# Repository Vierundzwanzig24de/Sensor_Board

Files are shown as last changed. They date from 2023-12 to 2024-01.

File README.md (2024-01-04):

# Sensor Board V1

## Platine in Betrieb nehmen:
1. Keine Fuses einlöten, reverse polarity testen (Q1201)
	- Q1201 Pin 3 liegt Versorgungsspannung an
	- V_IN LED (D1210) leuchtet
	- F_Vdrive einlöten, Vdrive LED (D1206) leuchtet
2. Buck converter:
	- F_BUCK (F1201) einlöten
	- U1201 Pin 1 liegen 6V an
	- U1202 Pin 2 liegen 5V an
	- U1203 Pin 2 liegen 5V an
3. LDOs:
	- F_5VA, F_5V und F_3V3 nacheinander einlöten und Ausgänge testen
	- 5VA, 5V und 3.3V LEDs leuchten auf
	- Versorgung wegnehmen und F_USB einlöten
	- USB Versorgung anschließen
	- V_IN, Vdrive und 5VA LEDs bleiben aus, 5V und 3.3V leuchten
	- USB Jumper links setzen (Pins 2+3), 5VA LED leuchtet
	- Spannung an U1203 Pin 2 ist ~0V
	- USB Jumper alle Pins verbinden
	- Spannung an U1202 Pin 2 ist ~0V
	- Eingangsspannung verbinden, V_IN und Vdrive leuchten, Stromverbrauch normal
	- Spannung über D1204 und D1205 messen, danach USB Jumper rechts setzen (Pins 1+2)
	- USB Versorgung trennen, Ausgangsspannung U1202 vergleichen zwischen USB und ohne -> D1204 überbrücken? Wenn ja, Jumper USB nur noch wechseln zwischen 1/2 und 2/3
4. STM32:
	- ST-Link verbinden und Testprogramm aufspielen
	- STATUS LED blinkt
	- Versorgungsspannung wegnehmen
	- USB Versorgung verbinden und erneut Testprogramm aufspielen
	- STATUS LED blinkt immer noch
	
## Prüfen:
- 74HC595 Ausgangsspannung an PU/PD Widerständen!
- Flankensteilheit Halbbrücken einstellen

## Für V2:
- Halbbrücken näher an Stecker (Halbbrücken, 1A-Profets, Buck converter)
- STM um 90° drehen
- USB Stecker weiter herausstehen lassen
- kleinere Gehäuse für ICs nutzen
- Level shifter für 74HC595 nicht notwendig
- 3.3V Outputs??
- Umschalten Ausgangsspannung per Software
- Umschalten USB Versorgung per Software?? (Falls keine Eingangsspannung messbar)
- CAN schaltbare Terminierung
- Vierundzwanzig24 Logo!!!
- AMPSEAL um 0.8mm (0.7mm?) nach innen verschieben

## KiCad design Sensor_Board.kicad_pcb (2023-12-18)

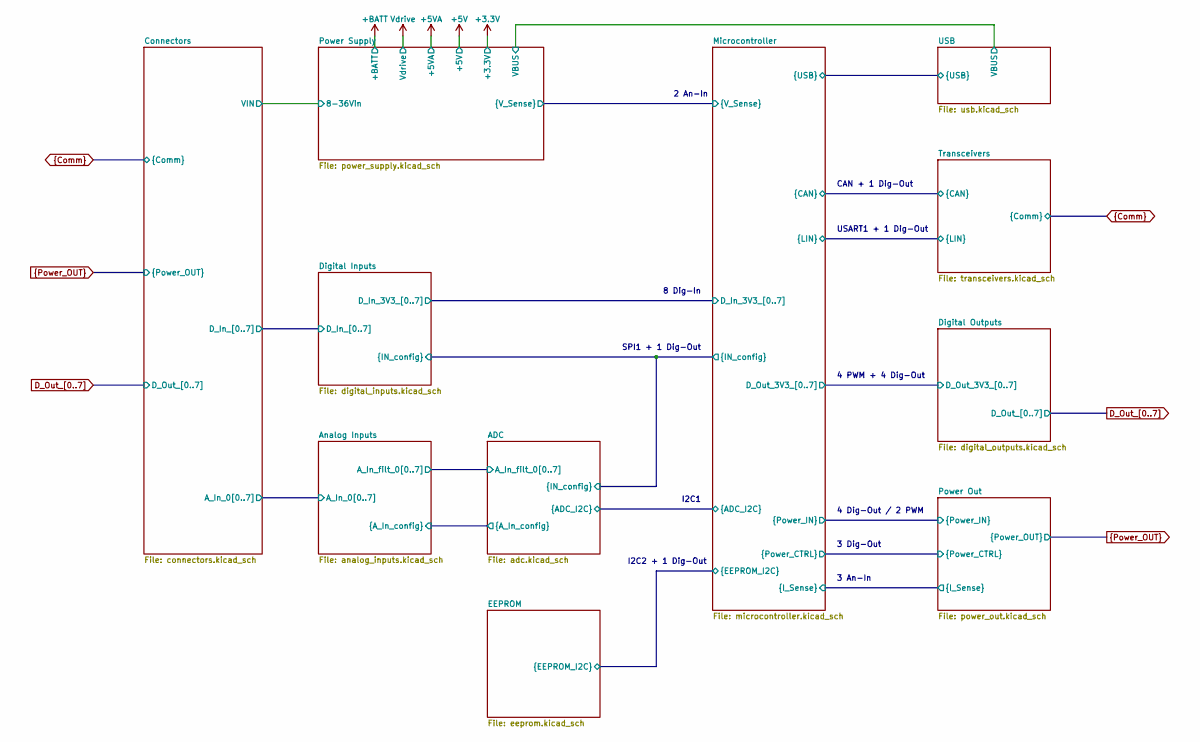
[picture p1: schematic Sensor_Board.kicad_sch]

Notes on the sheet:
I2C1
SPI1 + 1 Dig-Out
3 An-In
CAN + 1 Dig-Out
4 Dig-Out / 2 PWM
USART1 + 1 Dig-Out
I2C2 + 1 Dig-Out
3 Dig-Out
4 PWM + 4 Dig-Out
8 Dig-In
2 An-In

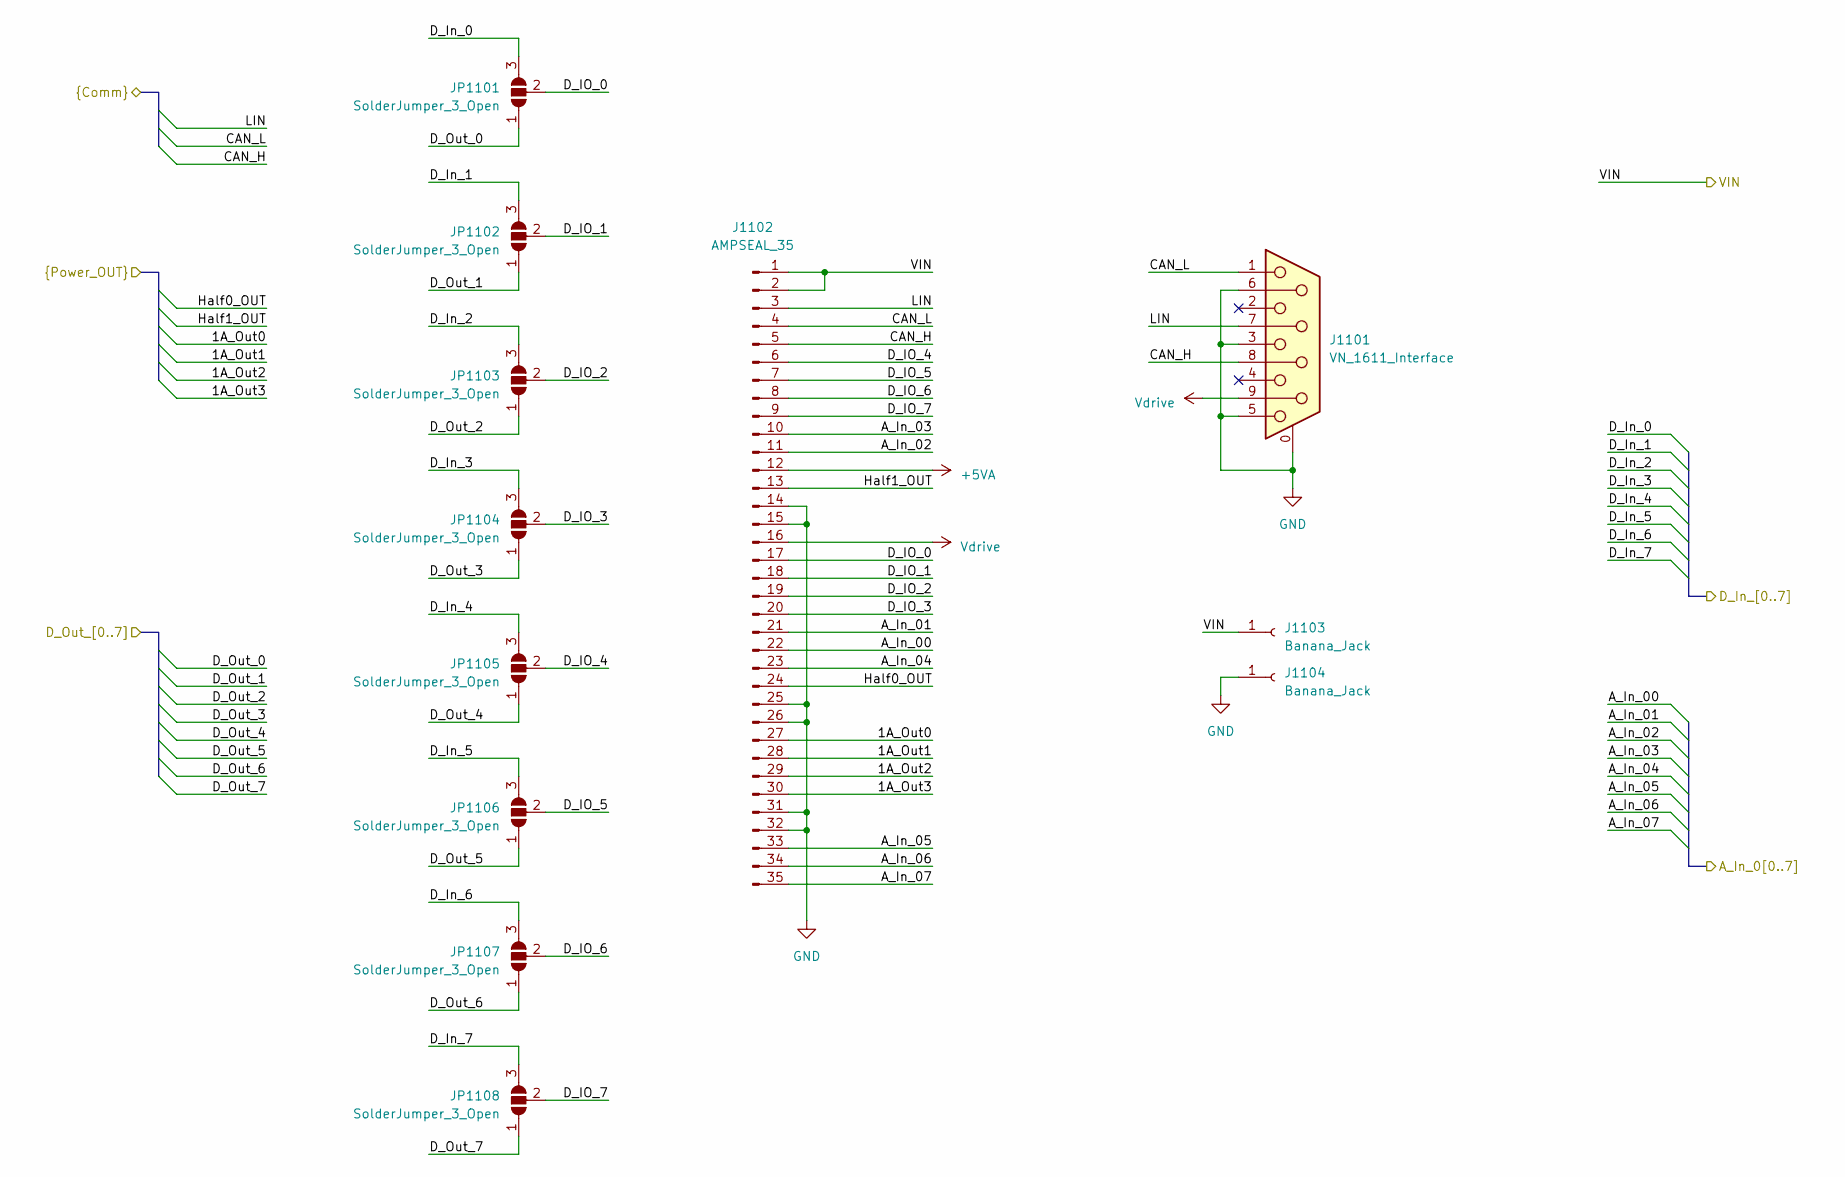
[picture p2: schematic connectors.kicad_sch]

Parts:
J1101: VN_1611_Interface; DSUB-9_Female_Horizontal_P2.77x2.84mm_EdgePinOffset9.90mm_H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
J1102: AMPSEAL_35
J1103, J1104: Banana_Jack; Banana_Cliff_FCR7350x_S16N-PC_Horizontal
JP1101, JP1102, JP1103, JP1104, JP1105, JP1106, JP1107, JP1108: SolderJumper_3_Open; SolderJumper-3_P1.3mm_Open_Pad1.0x1.5mm

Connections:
1A_Out1: J1102.28; also elsewhere on the board
1A_Out2: J1102.29; also elsewhere on the board
+5VA: J1102.12; also elsewhere on the board
/Analog Inputs/A_In_00: J1102.22; also elsewhere on the board
/Analog Inputs/A_In_01: J1102.21; also elsewhere on the board
/Analog Inputs/A_In_02: J1102.11; also elsewhere on the board
/Analog Inputs/A_In_03: J1102.10; also elsewhere on the board
/Analog Inputs/A_In_04: J1102.23; also elsewhere on the board
/Analog Inputs/A_In_05: J1102.33; also elsewhere on the board
/Analog Inputs/A_In_06: J1102.34; also elsewhere on the board
/Analog Inputs/A_In_07: J1102.35; also elsewhere on the board
/Connectors/D_IO_0: J1102.17, JP1101.2 (C)
/Connectors/D_IO_1: J1102.18, JP1102.2 (C)
/Connectors/D_IO_2: J1102.19, JP1103.2 (C)
/Connectors/D_IO_3: J1102.20, JP1104.2 (C)
/Connectors/D_IO_4: J1102.6, JP1105.2 (C)
/Connectors/D_IO_5: J1102.7, JP1106.2 (C)
/Connectors/D_IO_6: J1102.8, JP1107.2 (C)
/Connectors/D_IO_7: J1102.9, JP1108.2 (C)
/Connectors/D_In_0: JP1101.3 (B); also elsewhere on the board
/Connectors/D_In_1: JP1102.3 (B); also elsewhere on the board
/Connectors/D_In_2: JP1103.3 (B); also elsewhere on the board
/Connectors/D_In_3: JP1104.3 (B); also elsewhere on the board
/Connectors/D_In_4: JP1105.3 (B); also elsewhere on the board
/Connectors/D_In_5: JP1106.3 (B); also elsewhere on the board
/Connectors/D_In_6: JP1107.3 (B); also elsewhere on the board
/Connectors/D_In_7: JP1108.3 (B); also elsewhere on the board
/Connectors/VIN: J1102.1, J1102.2, J1103.1; also elsewhere on the board
CAN_H: J1101.8, J1102.5; also elsewhere on the board
CAN_L: J1101.1, J1102.4; also elsewhere on the board
D_Out_0: JP1101.1 (A); also elsewhere on the board
D_Out_1: JP1102.1 (A); also elsewhere on the board
D_Out_2: JP1103.1 (A); also elsewhere on the board
D_Out_3: JP1104.1 (A); also elsewhere on the board
D_Out_4: JP1105.1 (A); also elsewhere on the board
D_Out_5: JP1106.1 (A); also elsewhere on the board
D_Out_6: JP1107.1 (A); also elsewhere on the board
D_Out_7: JP1108.1 (A); also elsewhere on the board
Half0_OUT: J1102.24; also elsewhere on the board
Half1_OUT: J1102.13; also elsewhere on the board
LIN: J1101.7, J1102.3; also elsewhere on the board

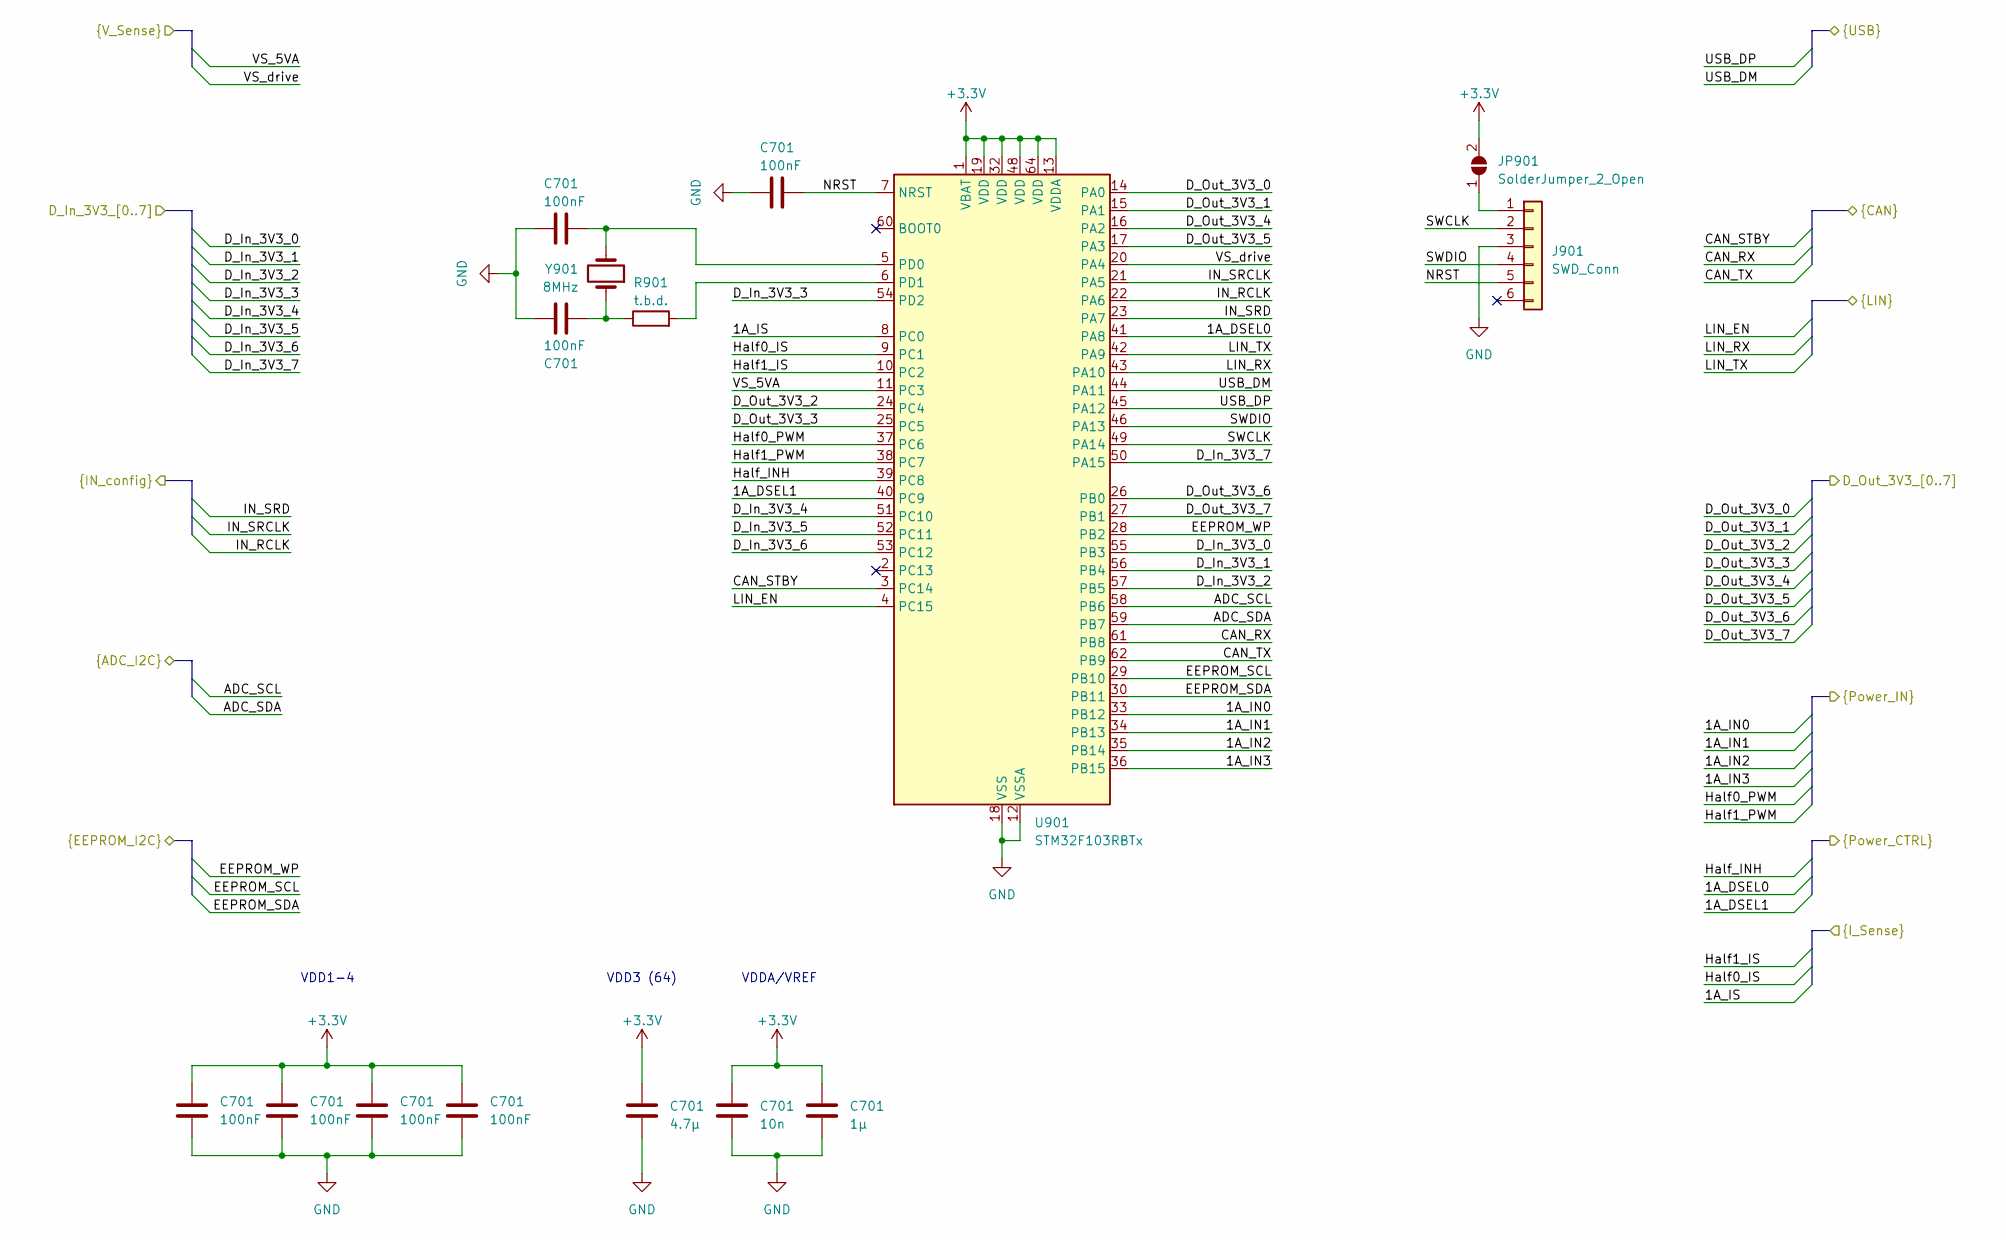
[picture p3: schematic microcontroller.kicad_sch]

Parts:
C701: 100nF; C_0603_1608Metric
J901: SWD_Conn; PinHeader_1x06_P2.54mm_Vertical
JP901: SolderJumper_2_Open; SolderJumper-2_P1.3mm_Open_Pad1.0x1.5mm
R901: t.b.d.; R_0603_1608Metric
U901: STM32F103RBTx; LQFP-64_10x10mm_P0.5mm
Y901: 8MHz; Crystal_SMD_3225-4Pin_3.2x2.5mm

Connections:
/ADC/ADC_SCL: U901.58 (PB6); also elsewhere on the board
/ADC/ADC_SDA: U901.59 (PB7); also elsewhere on the board
/ADC/IN_RCLK: U901.22 (PA6); also elsewhere on the board
/ADC/IN_SRCLK: U901.21 (PA5); also elsewhere on the board
/ADC/IN_SRD: U901.23 (PA7); also elsewhere on the board
/Digital Inputs/D_In_3V3_0: U901.55 (PB3); also elsewhere on the board
/Digital Inputs/D_In_3V3_1: U901.56 (PB4); also elsewhere on the board
/Digital Inputs/D_In_3V3_2: U901.57 (PB5); also elsewhere on the board
/Digital Inputs/D_In_3V3_3: U901.54 (PD2); also elsewhere on the board
/Digital Inputs/D_In_3V3_4: U901.51 (PC10); also elsewhere on the board
/Digital Inputs/D_In_3V3_5: U901.52 (PC11); also elsewhere on the board
/Digital Inputs/D_In_3V3_6: U901.53 (PC12); also elsewhere on the board
/Digital Inputs/D_In_3V3_7: U901.50 (PA15); also elsewhere on the board
/Digital Outputs/D_Out_3V3_0: U901.14 (PA0); also elsewhere on the board
/Digital Outputs/D_Out_3V3_1: U901.15 (PA1); also elsewhere on the board
/Digital Outputs/D_Out_3V3_2: U901.24 (PC4); also elsewhere on the board
/Digital Outputs/D_Out_3V3_3: U901.25 (PC5); also elsewhere on the board
/Digital Outputs/D_Out_3V3_4: U901.16 (PA2); also elsewhere on the board
/Digital Outputs/D_Out_3V3_5: U901.17 (PA3); also elsewhere on the board
/Digital Outputs/D_Out_3V3_6: U901.26 (PB0); also elsewhere on the board
/Digital Outputs/D_Out_3V3_7: U901.27 (PB1); also elsewhere on the board
/EEPROM/EEPROM_SCL: U901.29 (PB10); also elsewhere on the board
/EEPROM/EEPROM_SDA: U901.30 (PB11); also elsewhere on the board
/EEPROM/EEPROM_WP: U901.28 (PB2); also elsewhere on the board
/Microcontroller/1A_DSEL0: U901.41 (PA8); also elsewhere on the board
/Microcontroller/1A_DSEL1: U901.40 (PC9); also elsewhere on the board
/Microcontroller/1A_IN0: U901.33 (PB12); also elsewhere on the board
/Microcontroller/1A_IN1: U901.34 (PB13); also elsewhere on the board
/Microcontroller/1A_IN2: U901.35 (PB14); also elsewhere on the board
/Microcontroller/1A_IN3: U901.36 (PB15); also elsewhere on the board
/Microcontroller/1A_IS: U901.8 (PC0); also elsewhere on the board
/Microcontroller/CAN_RX: U901.61 (PB8); also elsewhere on the board
/Microcontroller/CAN_STBY: U901.3 (PC14); also elsewhere on the board
/Microcontroller/CAN_TX: U901.62 (PB9); also elsewhere on the board
/Microcontroller/Half0_IS: U901.9 (PC1); also elsewhere on the board
/Microcontroller/Half0_PWM: U901.37 (PC6); also elsewhere on the board
/Microcontroller/Half1_IS: U901.10 (PC2); also elsewhere on the board
/Microcontroller/Half1_PWM: U901.38 (PC7); also elsewhere on the board
/Microcontroller/Half_INH: U901.39 (PC8); also elsewhere on the board
/Microcontroller/LIN_EN: U901.4 (PC15); also elsewhere on the board
/Microcontroller/LIN_RX: U901.43 (PA10); also elsewhere on the board
/Microcontroller/LIN_TX: U901.42 (PA9); also elsewhere on the board
/Microcontroller/SWCLK: J901.2, U901.49 (PA14)
/Microcontroller/SWDIO: J901.4, U901.46 (PA13)
/Microcontroller/USB_DM: U901.44 (PA11); also elsewhere on the board
/Microcontroller/USB_DP: U901.45 (PA12); also elsewhere on the board
/Microcontroller/VS_5VA: U901.11 (PC3); also elsewhere on the board
/Microcontroller/VS_drive: U901.20 (PA4); also elsewhere on the board
unnamed: J901.1, JP901.1 (A)
unnamed: R901.2, U901.6 (PD1)

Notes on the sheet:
VDD3 (64)
VDDA/VREF
VDD1-4

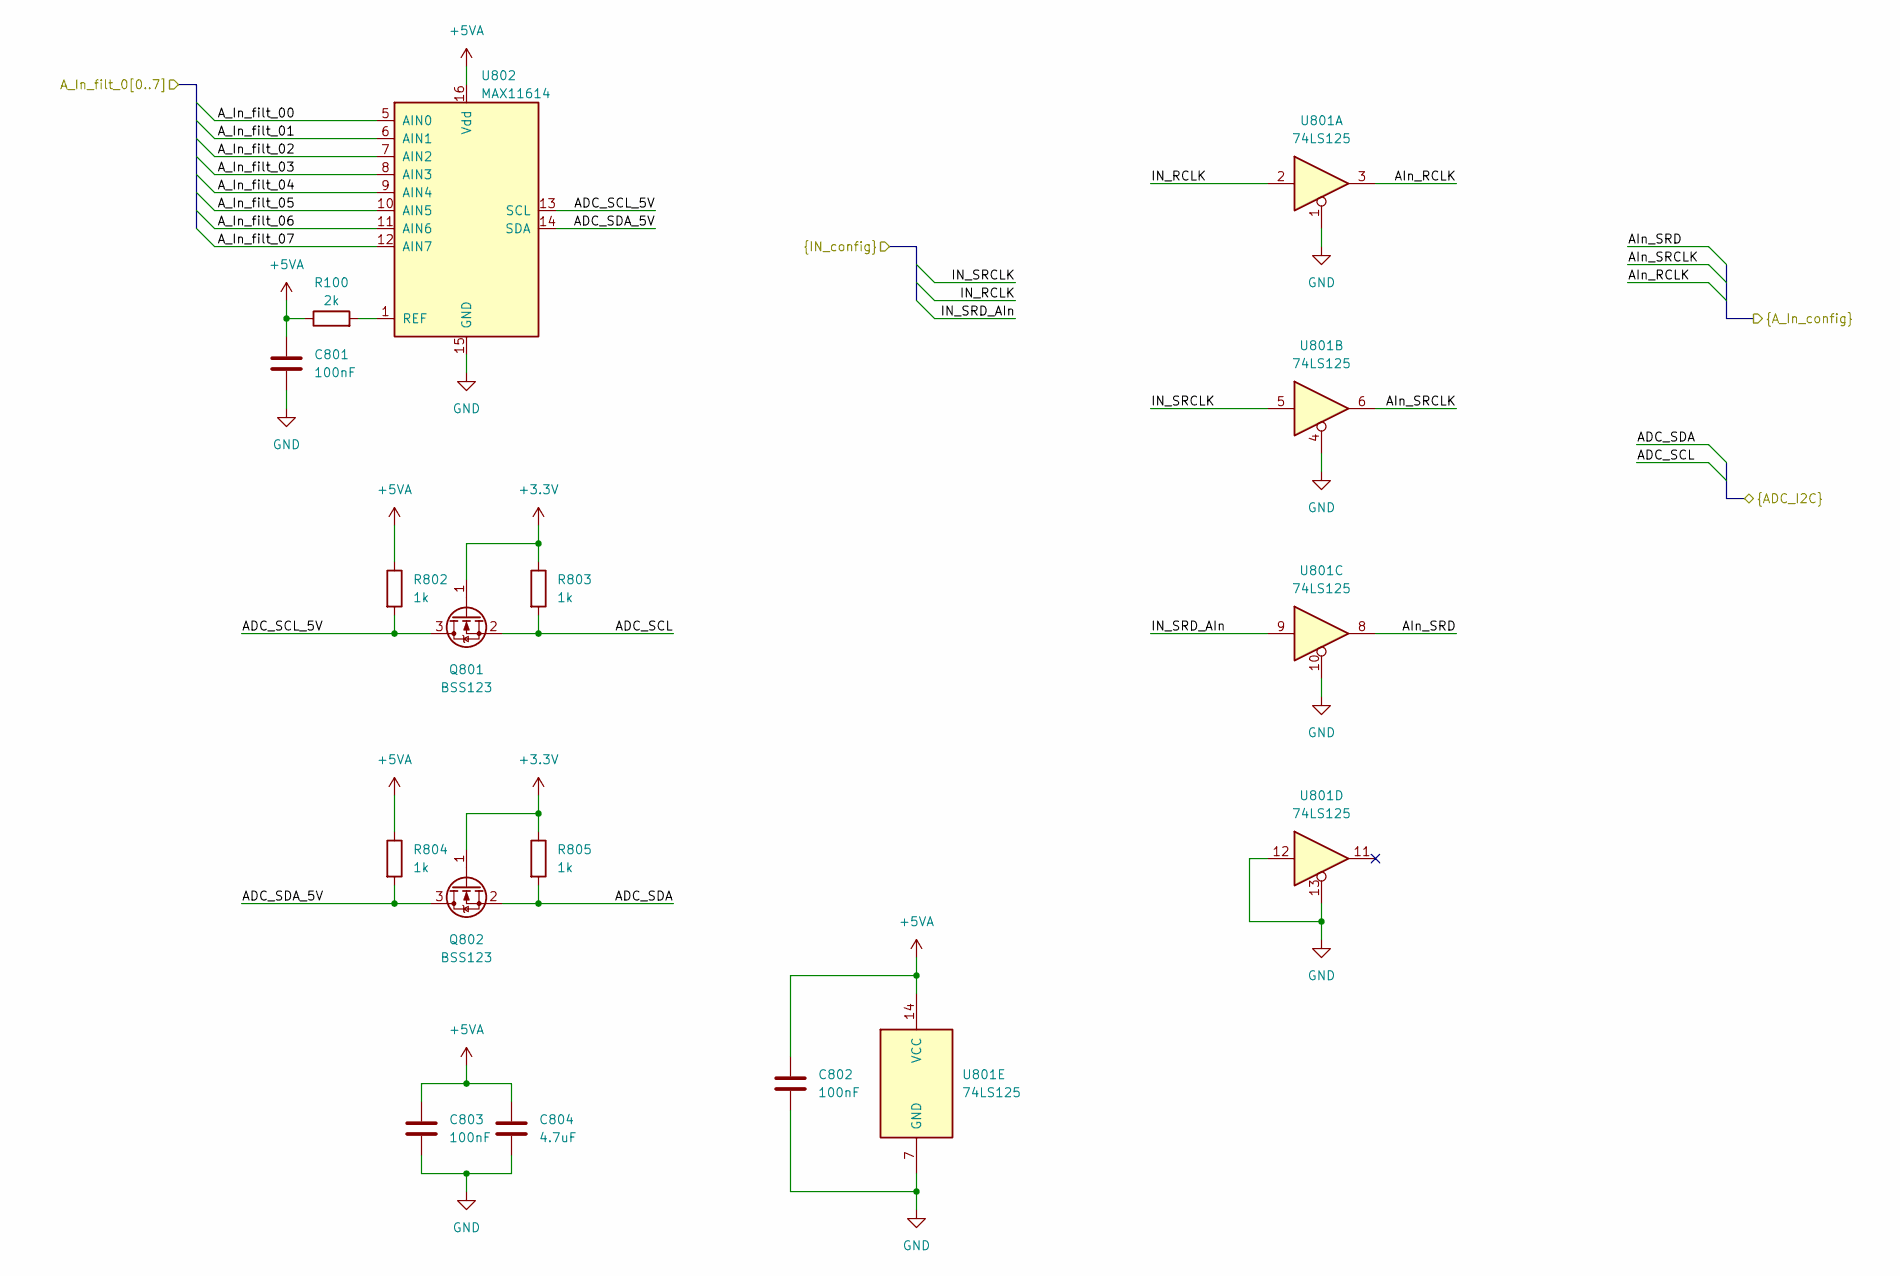
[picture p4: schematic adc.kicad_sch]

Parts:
C801, C802, C803: 100nF; C_0603_1608Metric
C804: 4.7uF; C_0805_2012Metric
Q801, Q802: BSS123; SOT-23
R100: 2k; R_0603_1608Metric
R802, R803, R804, R805: 1k; R_0603_1608Metric
U801: 74LS125; SOIC-16_3.9x9.9mm_P1.27mm
U802: MAX11614; QSOP-16_3.9x4.9mm_P0.635mm

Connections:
+5VA: C801.1, C802.1, C803.1, C804.1, R802.1, R804.1, U801.14 (VCC), U802.16 (Vdd); also elsewhere on the board
/ADC/ADC_SCL: Q801.2 (S), R803.2; also elsewhere on the board
/ADC/ADC_SCL_5V: Q801.3 (D), R802.2, U802.13 (SCL)
/ADC/ADC_SDA: Q802.2 (S), R805.2; also elsewhere on the board
/ADC/ADC_SDA_5V: Q802.3 (D), R804.2, U802.14 (SDA)
/ADC/AIn_RCLK: U801.3; also elsewhere on the board
/ADC/AIn_SRCLK: U801.6; also elsewhere on the board
/ADC/AIn_SRD: U801.8; also elsewhere on the board
/ADC/A_In_filt_00: U802.5 (AIN0); also elsewhere on the board
/ADC/A_In_filt_01: U802.6 (AIN1); also elsewhere on the board
/ADC/A_In_filt_02: U802.7 (AIN2); also elsewhere on the board
/ADC/A_In_filt_03: U802.8 (AIN3); also elsewhere on the board
/ADC/A_In_filt_04: U802.9 (AIN4); also elsewhere on the board
/ADC/A_In_filt_05: U802.10 (AIN5); also elsewhere on the board
/ADC/A_In_filt_06: U802.11 (AIN6); also elsewhere on the board
/ADC/A_In_filt_07: U802.12 (AIN7); also elsewhere on the board
/ADC/IN_RCLK: U801.2; also elsewhere on the board
/ADC/IN_SRCLK: U801.5; also elsewhere on the board
/ADC/IN_SRD_AIn: U801.9; also elsewhere on the board
unnamed 245: U802.1 (REF); also elsewhere on the board

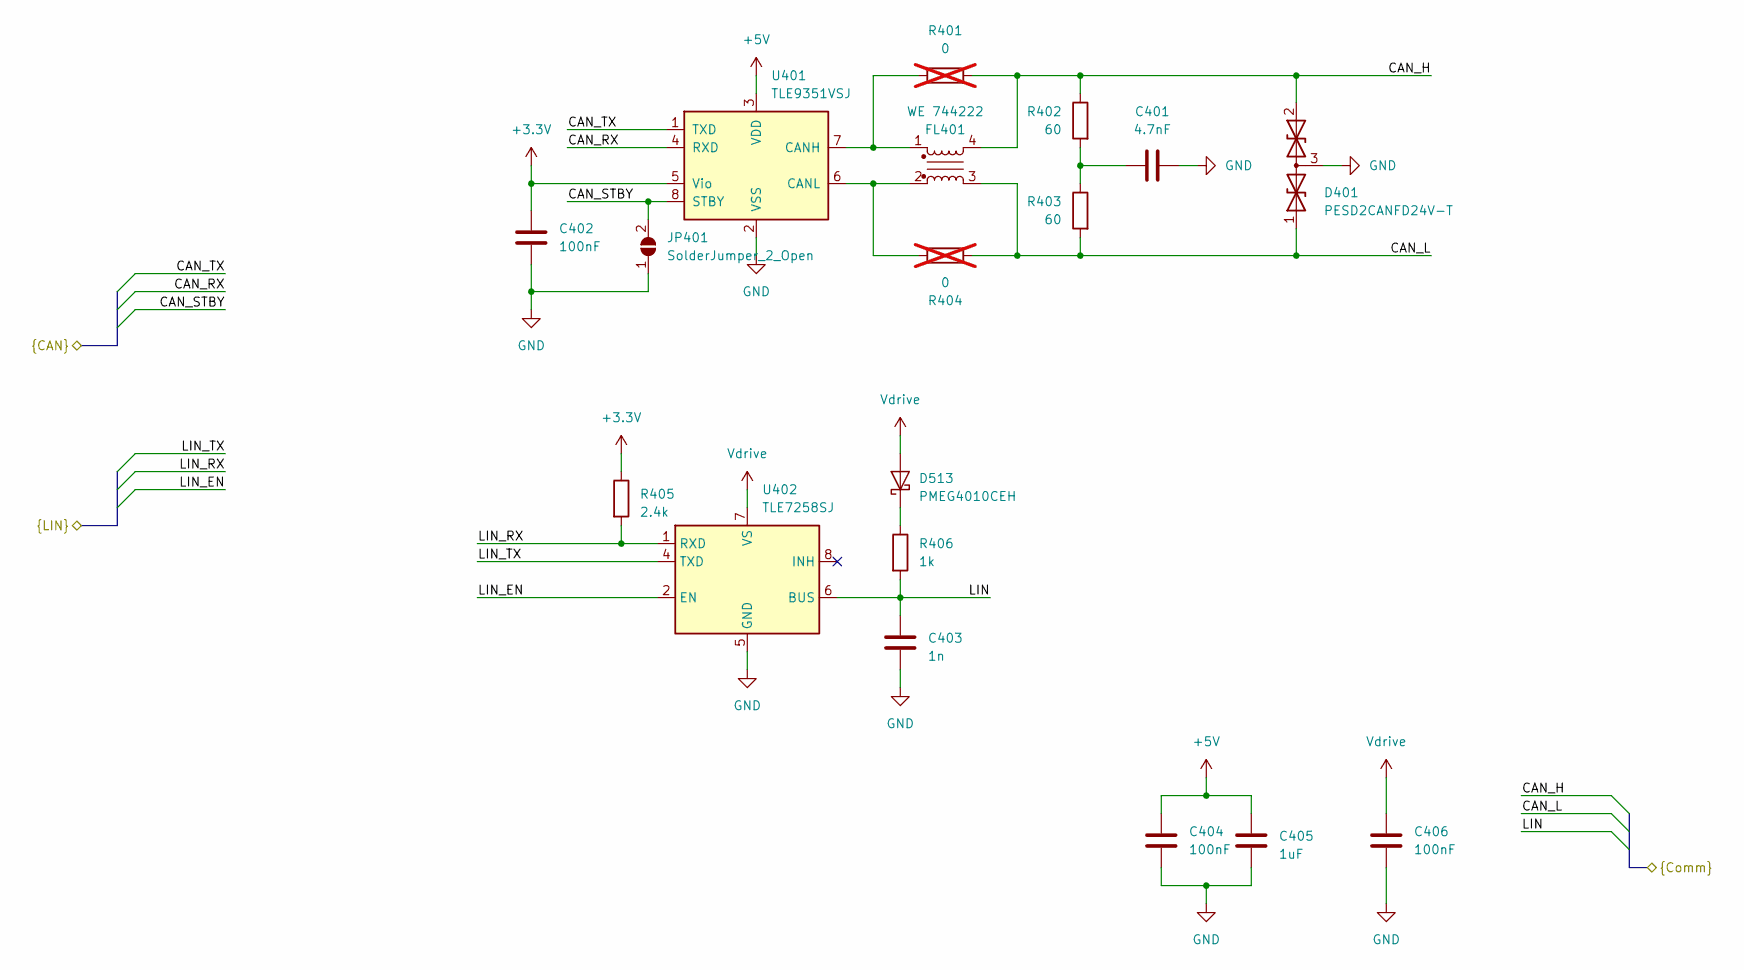
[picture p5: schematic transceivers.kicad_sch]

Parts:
C401: 4.7nF; C_0603_1608Metric
C402, C404, C406: 100nF; C_0603_1608Metric
C403: 1n; C_0603_1608Metric
C405: 1uF; C_0603_1608Metric
D401: PESD2CANFD24V-T; SOT-23-3
D513: PMEG4010CEH; D_SOD-123F
FL401: WE 744222; L_CommonMode_Wuerth_WE-SL2
JP401: SolderJumper_2_Open; SolderJumper-2_P1.3mm_Open_Pad1.0x1.5mm
R401, R404: 0; R_0603_1608Metric; not fitted
R402, R403: 60; R_0603_1608Metric
R405: 2.4k; R_0603_1608Metric
R406: 1k; R_1206_3216Metric
U401: TLE9351VSJ; SOIC-8_3.9x4.9mm_P1.27mm
U402: TLE7258SJ; SOIC-8_3.9x4.9mm_P1.27mm

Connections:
+5V: C404.1, C405.1, U401.3 (VDD); also elsewhere on the board
/Microcontroller/CAN_RX: U401.4 (RXD); also elsewhere on the board
/Microcontroller/CAN_STBY: JP401.2 (B), U401.8 (STBY); also elsewhere on the board
/Microcontroller/CAN_TX: U401.1 (TXD); also elsewhere on the board
/Microcontroller/LIN_EN: U402.2 (EN); also elsewhere on the board
/Microcontroller/LIN_RX: R405.2, U402.1 (RXD); also elsewhere on the board
/Microcontroller/LIN_TX: U402.4 (TXD); also elsewhere on the board
CAN_H: D401.2 (A2), FL401.4, R401.2, R402.1; also elsewhere on the board
CAN_L: D401.1 (A1), FL401.3, R403.2, R404.2; also elsewhere on the board
LIN: C403.1, R406.2, U402.6 (BUS); also elsewhere on the board
unnamed: C401.1, R402.2, R403.1
unnamed: FL401.1, R401.1, U401.7 (CANH)
unnamed: FL401.2, R404.1, U401.6 (CANL)

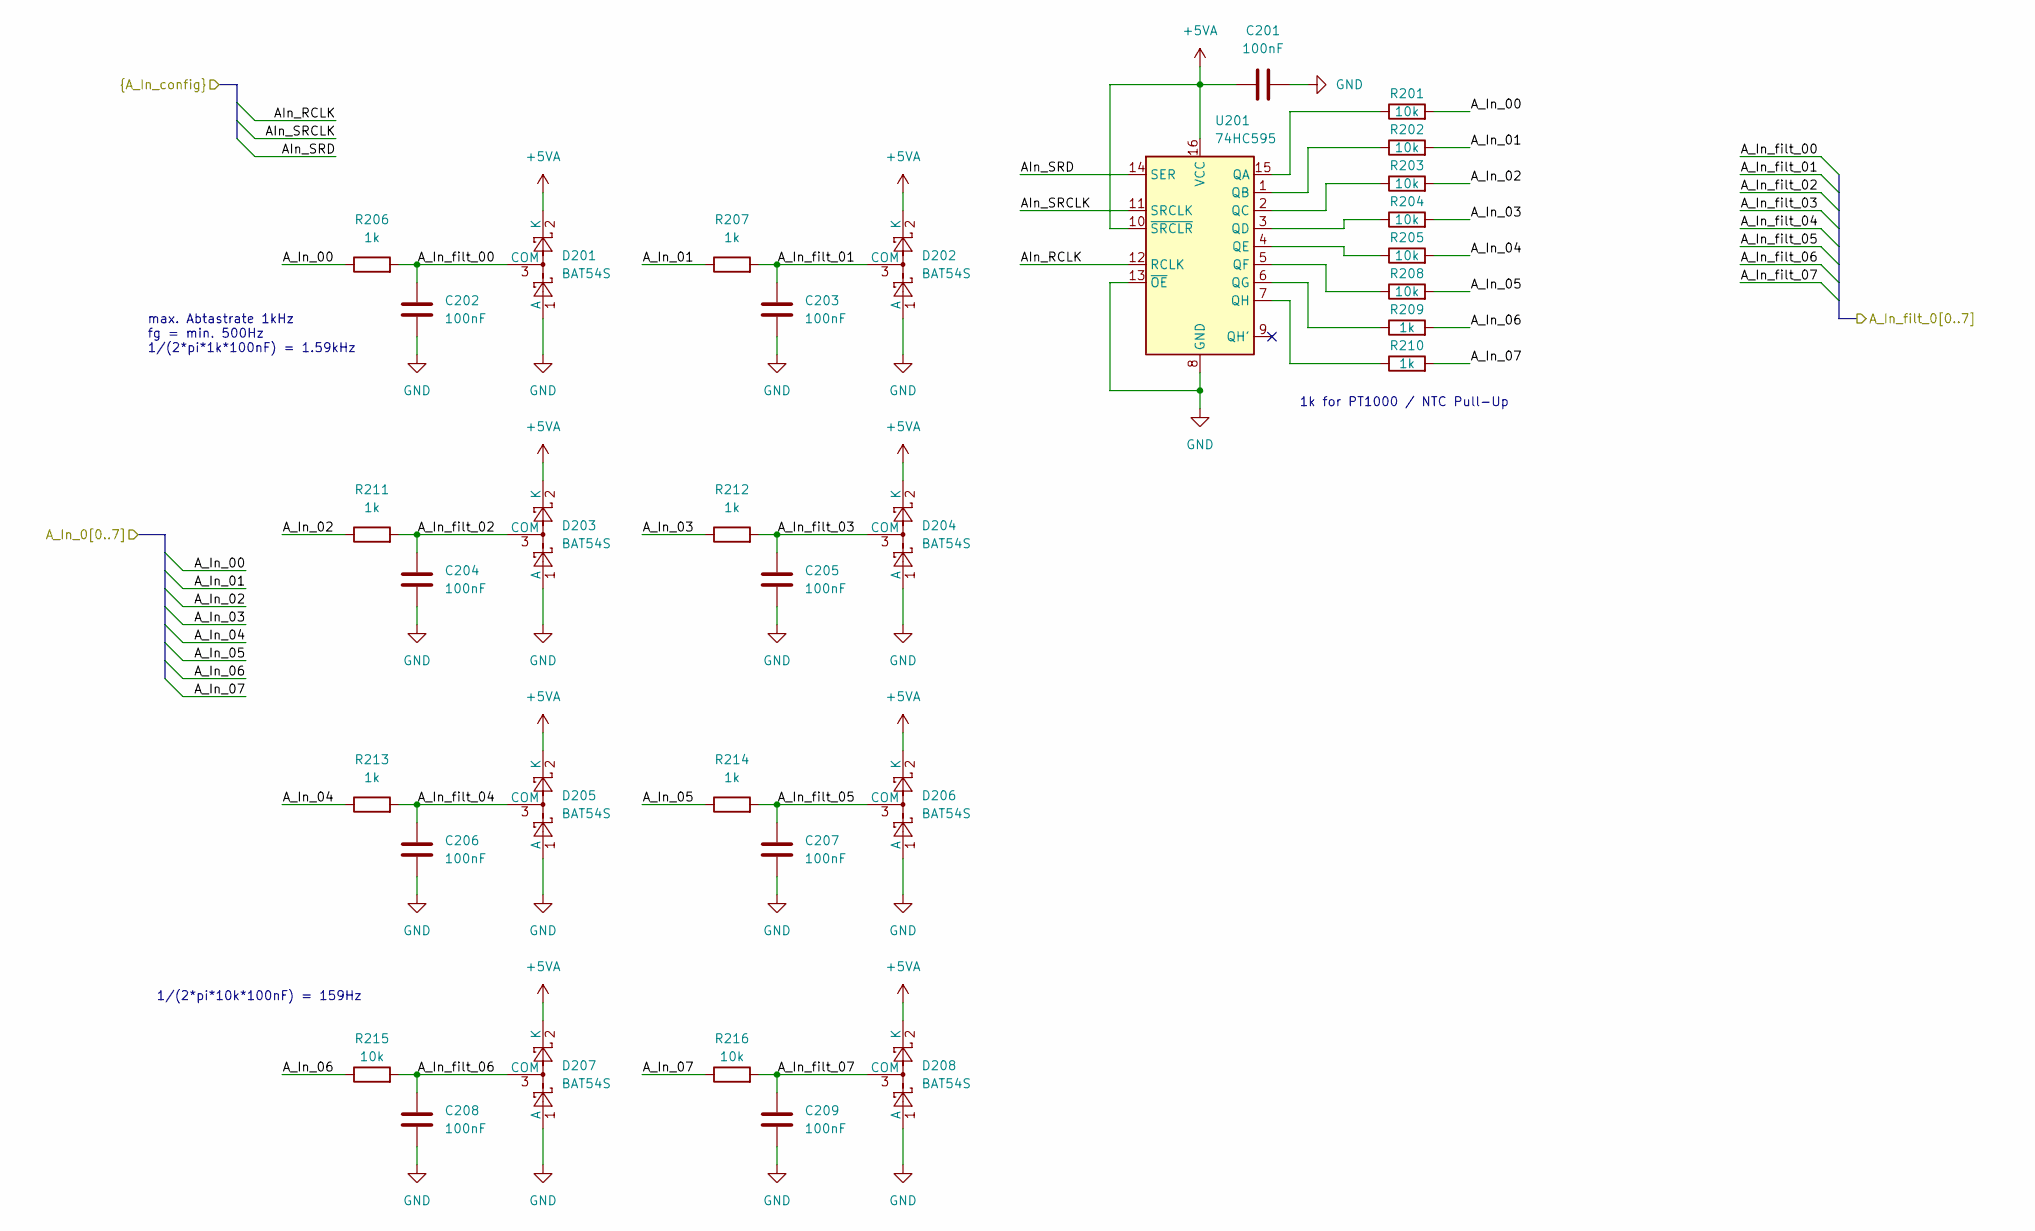
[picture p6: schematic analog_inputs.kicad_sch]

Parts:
C201, C202, C203, C204, C205, C206, C207, C208, C209: 100nF; C_0603_1608Metric
D201, D202, D203, D204, D205, D206, D207, D208: BAT54S; SOT-23
R201, R202, R203, R204, R205, R208, R215, R216: 10k; R_0603_1608Metric
R206, R207, R209, R210, R211, R212, R213, R214: 1k; R_0603_1608Metric
U201: 74HC595; SOIC-16_3.9x9.9mm_P1.27mm

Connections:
+5VA: C201.1, D201.2 (K), D202.2 (K), D203.2 (K), D204.2 (K), D205.2 (K), D206.2 (K), D207.2 (K), D208.2 (K), U201.10 (~SRCLR), U201.16 (VCC); also elsewhere on the board
/ADC/AIn_RCLK: U201.12 (RCLK); also elsewhere on the board
/ADC/AIn_SRCLK: U201.11 (SRCLK); also elsewhere on the board
/ADC/AIn_SRD: U201.14 (SER); also elsewhere on the board
/ADC/A_In_filt_00: C202.1, D201.3 (COM), R206.2; also elsewhere on the board
/ADC/A_In_filt_01: C203.1, D202.3 (COM), R207.2; also elsewhere on the board
/ADC/A_In_filt_02: C204.1, D203.3 (COM), R211.2; also elsewhere on the board
/ADC/A_In_filt_03: C205.1, D204.3 (COM), R212.2; also elsewhere on the board
/ADC/A_In_filt_04: C206.1, D205.3 (COM), R213.2; also elsewhere on the board
/ADC/A_In_filt_05: C207.1, D206.3 (COM), R214.2; also elsewhere on the board
/ADC/A_In_filt_06: C208.1, D207.3 (COM), R215.2; also elsewhere on the board
/ADC/A_In_filt_07: C209.1, D208.3 (COM), R216.2; also elsewhere on the board
/Analog Inputs/A_In_00: R201.2, R206.1; also elsewhere on the board
/Analog Inputs/A_In_01: R202.2, R207.1; also elsewhere on the board
/Analog Inputs/A_In_02: R203.2, R211.1; also elsewhere on the board
/Analog Inputs/A_In_03: R204.2, R212.1; also elsewhere on the board
/Analog Inputs/A_In_04: R205.2, R213.1; also elsewhere on the board
/Analog Inputs/A_In_05: R208.2, R214.1; also elsewhere on the board
/Analog Inputs/A_In_06: R209.2, R215.1; also elsewhere on the board
/Analog Inputs/A_In_07: R210.2, R216.1; also elsewhere on the board
unnamed: R201.1, U201.15 (QA)
unnamed: R202.1, U201.1 (QB)
unnamed: R203.1, U201.2 (QC)
unnamed: R204.1, U201.3 (QD)
unnamed: R205.1, U201.4 (QE)
unnamed: R208.1, U201.5 (QF)
unnamed: R209.1, U201.6 (QG)
unnamed: R210.1, U201.7 (QH)

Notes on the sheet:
1k for PT1000 / NTC Pull-Up
1/(2*pi*10k*100nF) = 159Hz
max. Abtastrate 1kHz fg = min. 500Hz 1/(2*pi*1k*100nF) = 1.59kHz

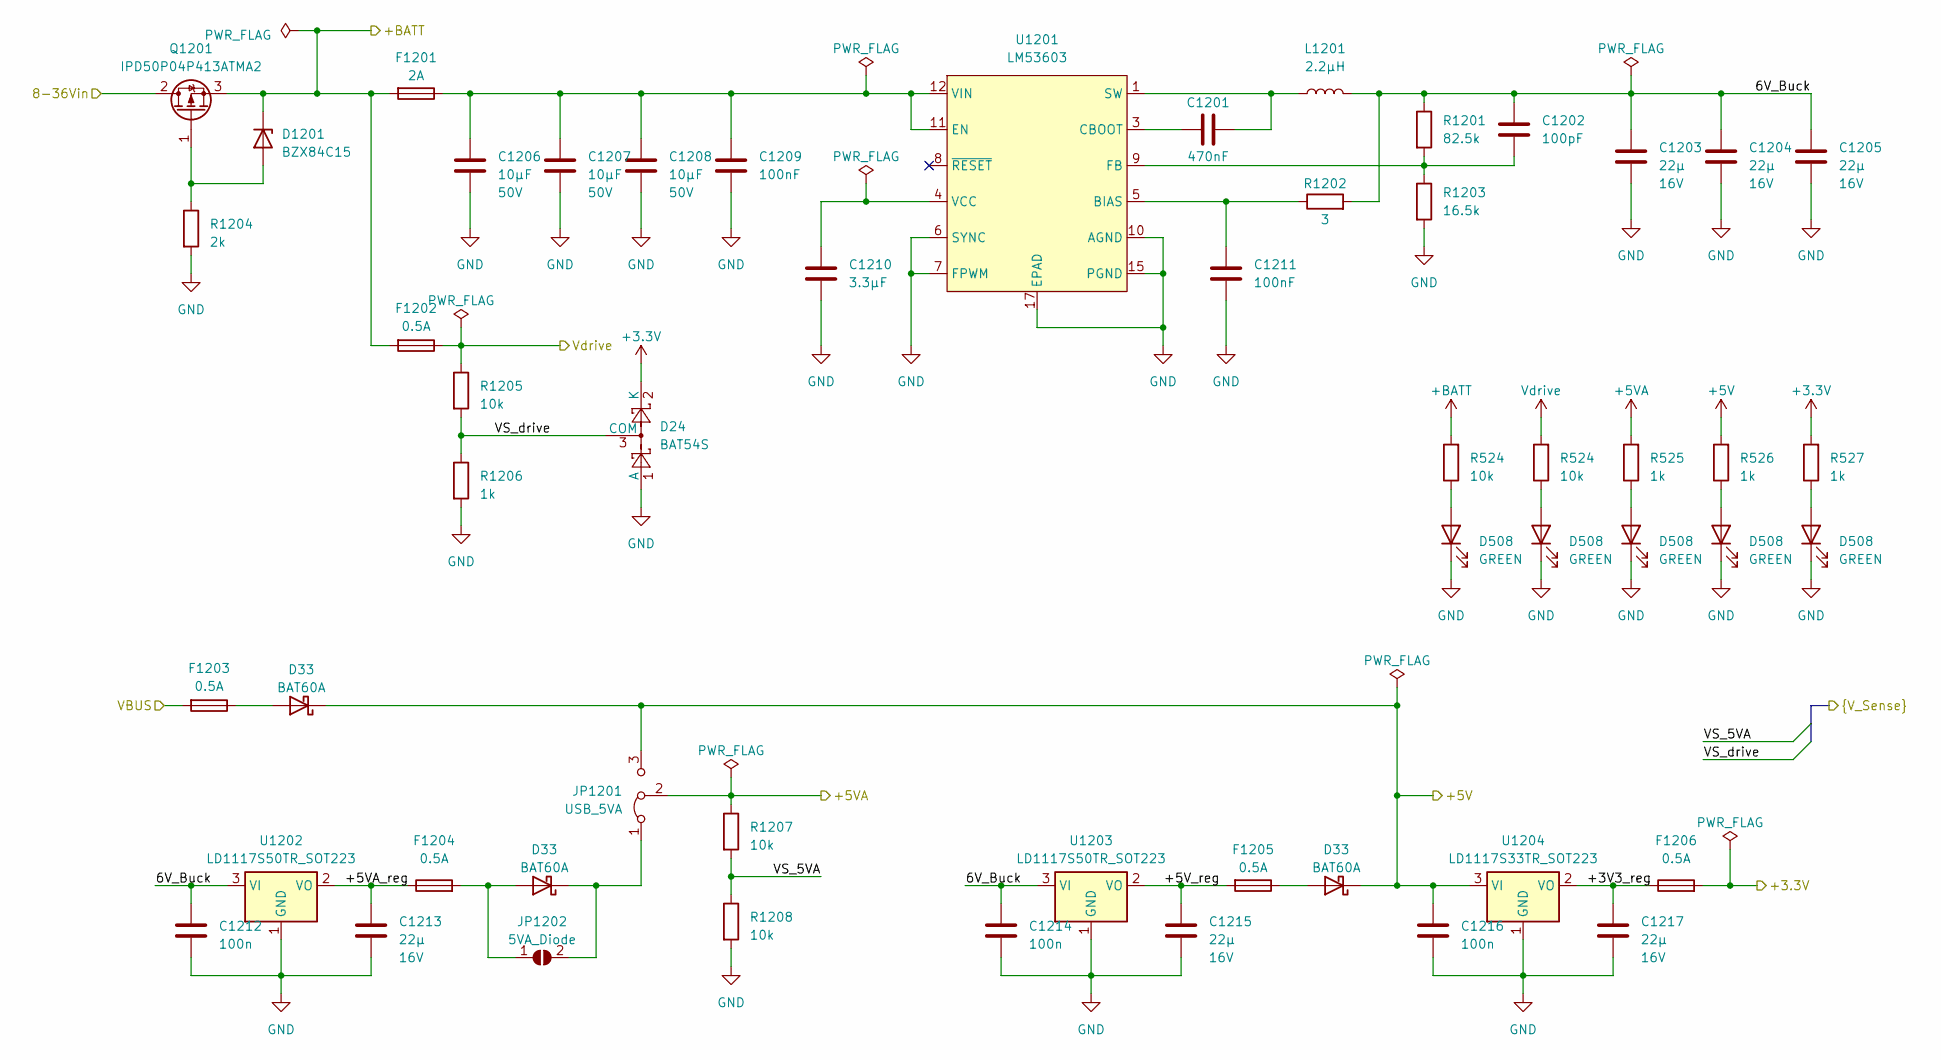
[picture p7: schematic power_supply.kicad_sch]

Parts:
C1201: 470nF; C_0805_2012Metric
C1202: 100pF; R_0603_1608Metric
C1203, C1204, C1205, C1213, C1215, C1217: 22µ; C_1210_3225Metric; Voltage 16V
C1206, C1207, C1208: 10µF; C_1206_3216Metric; Voltage 50V
C1209, C1211: 100nF; R_0603_1608Metric
C1210: 3.3µF; C_1206_3216Metric
C1212, C1214, C1216: 100n; C_0603_1608Metric
D24: BAT54S; SOT-23
D33: BAT60A; D_SOD-323
D508: GREEN; LED_0603_1608Metric
D1201: BZX84C15; SOT-23
F1201: 2A; Fuse_1206_3216Metric
F1202, F1203, F1204, F1205, F1206: 0.5A; Fuse_1206_3216Metric
JP1201: USB_5VA; PinHeader_1x03_P2.54mm_Vertical
JP1202: 5VA_Diode; SolderJumper-2_P1.3mm_Open_Pad1.0x1.5mm
L1201: 2.2µH; L_Bourns_SRP7028A_7.3x6.6mm
Q1201: IPD50P04P413ATMA2; TO-252-2
R524, R1205, R1207, R1208: 10k; R_0603_1608Metric
R525, R526, R527, R1206: 1k; R_0603_1608Metric
R1201: 82.5k; R_0603_1608Metric
R1202: 3; R_0603_1608Metric
R1203: 16.5k; R_0603_1608Metric
R1204: 2k; R_0603_1608Metric
U1201: LM53603; HTSSOP-16-1EP_4.4x5mm_P0.65mm_EP3.4x5mm_Mask2.46x2.31mm
U1202, U1203: LD1117S50TR_SOT223; SOT-223-3_TabPin2
U1204: LD1117S33TR_SOT223; SOT-223-3_TabPin2

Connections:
1A_Out1: R525.2; also elsewhere on the board
1A_Out2: R526.2; also elsewhere on the board
+5V: C1216.1, JP1201.3 (B), U1204.3 (VI); also elsewhere on the board
+5VA: JP1201.2 (C), R1207.1; also elsewhere on the board
+BATT: D1201.3 (K), F1201.2, F1202.2, Q1201.3 (S); also elsewhere on the board
/Connectors/VIN: Q1201.2 (D); also elsewhere on the board
/Microcontroller/VS_5VA: R1207.2, R1208.1; also elsewhere on the board
/Microcontroller/VS_drive: R1205.2, R1206.1; also elsewhere on the board
/Power Supply/6V_Buck: C1202.1, C1203.1, C1204.1, C1205.1, C1212.1, C1214.1, L1201.2, R1201.1, R1202.2, U1202.3 (VI), U1203.3 (VI)
/Power Supply/+3V3_reg: C1217.1, F1206.1, U1204.2 (VO)
/Power Supply/+5VA_reg: C1213.1, F1204.1, U1202.2 (VO)
/Power Supply/+5V_reg: C1215.1, F1205.2, U1203.2 (VO)
/Power Supply/VBUS: F1203.2; also elsewhere on the board
unnamed: C1201.2, L1201.1, U1201.1 (SW), U1201.2 (SW)
unnamed: D1201.1 (A), Q1201.1 (G), R1204.1
unnamed 151: F1203.1; also elsewhere on the board
unnamed 152: F1204.2, JP1202.1 (A); also elsewhere on the board
unnamed 153: JP1201.1 (A), JP1202.2 (B); also elsewhere on the board
unnamed 154: F1205.1; also elsewhere on the board
unnamed: C1211.1, R1202.1, U1201.5 (BIAS)
unnamed: C1201.1, U1201.3 (CBOOT)
unnamed: C1202.2, R1201.2, R1203.1, U1201.9 (FB)
unnamed: C1210.1, U1201.4 (VCC)
VIN: C1206.1, C1207.1, C1208.1, C1209.1, F1201.1, U1201.11 (EN), U1201.12 (VIN), U1201.13 (VIN)

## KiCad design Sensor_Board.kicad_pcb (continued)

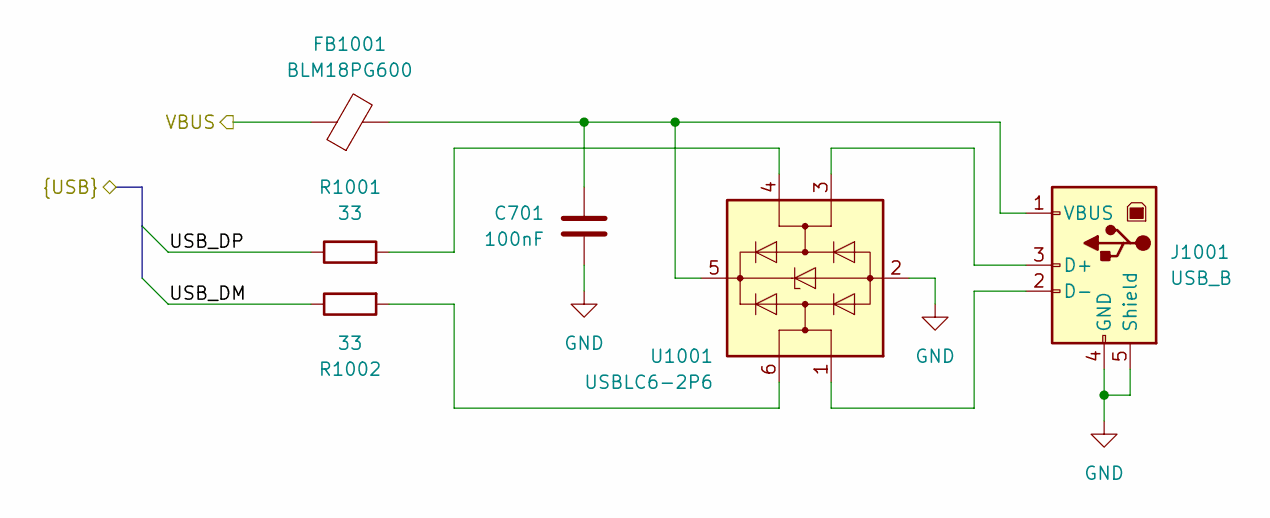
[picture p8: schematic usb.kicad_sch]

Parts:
C701: 100nF; C_0603_1608Metric
FB1001: BLM18PG600; L_0603_1608Metric
J1001: USB_B; USB_B_OST_USB-B1HSxx_Horizontal
R1001, R1002: 33; R_0603_1608Metric
U1001: USBLC6-2P6; SOT-666

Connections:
/Microcontroller/USB_DM: R1002.1; also elsewhere on the board
/Microcontroller/USB_DP: R1001.1; also elsewhere on the board
/Power Supply/VBUS: FB1001.1; also elsewhere on the board
unnamed: J1001.3 (D+), U1001.3 (I/O2)
unnamed: J1001.2 (D-), U1001.1 (I/O1)
unnamed: R1001.2, U1001.4 (I/O2)
unnamed: R1002.2, U1001.6 (I/O1)

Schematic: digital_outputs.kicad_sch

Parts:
D601, D602, D603, D604, D605, D606, D607, D608: BAT54S; SOT-23
JP601: DOut_Supply0; PinHeader_1x03_P2.54mm_Vertical
JP602: DOut_Supply1; PinHeader_1x03_P2.54mm_Vertical
Q601, Q602, Q603, Q604, Q605, Q606, Q607, Q608, Q613, Q614, Q615, Q616, Q617, Q618, Q619, Q620: BC817; SOT-23
Q609, Q610, Q611, Q612, Q621, Q622, Q623, Q624: BC807; SOT-23
R601, R603, R605, R607, R625, R627, R629, R631: 10k; R_0603_1608Metric
R602, R604, R606, R608, R609, R610, R611, R612, R613, R614, R615, R616, R617, R618, R619, R620, R621, R622, R623, R624, R626, R628, R630, R632, R633, R634, R635, R636, R637, R638, R639, R640, R641, R642, R643, R644, R645, R646, R647, R648: 1k; R_0603_1608Metric

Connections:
+5V: JP601.3 (B), JP602.3 (B); also elsewhere on the board
/Digital Outputs/DOut_Supply0: JP601.2 (C), Q601.3 (C), Q602.3 (C), Q603.3 (C), Q604.3 (C), R601.1, R603.1, R605.1, R607.1
/Digital Outputs/DOut_Supply1: JP602.2 (C), Q613.3 (C), Q614.3 (C), Q615.3 (C), Q616.3 (C), R625.1, R627.1, R629.1, R631.1
/Digital Outputs/D_Out_3V3_0: R617.1; also elsewhere on the board
/Digital Outputs/D_Out_3V3_1: R619.1; also elsewhere on the board
/Digital Outputs/D_Out_3V3_2: R621.1; also elsewhere on the board
/Digital Outputs/D_Out_3V3_3: R623.1; also elsewhere on the board
/Digital Outputs/D_Out_3V3_4: R641.1; also elsewhere on the board
/Digital Outputs/D_Out_3V3_5: R643.1; also elsewhere on the board
/Digital Outputs/D_Out_3V3_6: R645.1; also elsewhere on the board
/Digital Outputs/D_Out_3V3_7: R647.1; also elsewhere on the board
D_Out_0: D601.3; also elsewhere on the board
D_Out_1: D602.3; also elsewhere on the board
D_Out_2: D603.3; also elsewhere on the board
D_Out_3: D604.3; also elsewhere on the board
D_Out_4: D605.3; also elsewhere on the board
D_Out_5: D606.3; also elsewhere on the board
D_Out_6: D607.3; also elsewhere on the board
D_Out_7: D608.3; also elsewhere on the board
unnamed: D601.1, R609.2
unnamed: D601.2, R613.1
unnamed: D602.1, R610.2
unnamed: D602.2, R614.1
unnamed: D603.1, R611.2
unnamed: D603.2, R615.1
unnamed: D604.1, R612.2
unnamed: D604.2, R616.1
unnamed: D605.1, R633.2
unnamed: D605.2, R637.1
unnamed: D606.1, R634.2
unnamed: D606.2, R638.1
unnamed: D607.1, R635.2
unnamed: D607.2, R639.1
unnamed: D608.1, R636.2
unnamed: D608.2, R640.1
unnamed: Q601.1 (B), R602.1
unnamed: Q601.2 (E), R609.1
unnamed: Q602.1 (B), R604.1
unnamed: Q602.2 (E), R610.1
unnamed: Q603.1 (B), R606.1
unnamed: Q603.2 (E), R611.1
unnamed: Q604.1 (B), R608.1
unnamed: Q604.2 (E), R612.1
unnamed: Q605.1 (B), R617.2
unnamed: Q605.3 (C), R601.2, R602.2, R618.1
unnamed: Q606.1 (B), R619.2
unnamed: Q606.3 (C), R603.2, R604.2, R620.1
unnamed: Q607.1 (B), R621.2
unnamed: Q607.3 (C), R605.2, R606.2, R622.1
unnamed: Q608.1 (B), R623.2
unnamed: Q608.3 (C), R607.2, R608.2, R624.1
unnamed: Q609.1 (B), R618.2
unnamed: Q609.2 (E), R613.2
unnamed: Q610.1 (B), R620.2
unnamed: Q610.2 (E), R614.2
unnamed: Q611.1 (B), R622.2
unnamed: Q611.2 (E), R615.2
unnamed: Q612.1 (B), R624.2
unnamed: Q612.2 (E), R616.2
unnamed: Q613.1 (B), R626.1
unnamed: Q613.2 (E), R633.1
unnamed: Q614.1 (B), R628.1
unnamed: Q614.2 (E), R634.1
unnamed: Q615.1 (B), R630.1
unnamed: Q615.2 (E), R635.1
unnamed: Q616.1 (B), R632.1
unnamed: Q616.2 (E), R636.1
unnamed: Q617.1 (B), R641.2
unnamed: Q617.3 (C), R625.2, R626.2, R642.1
unnamed: Q618.1 (B), R643.2
unnamed: Q618.3 (C), R627.2, R628.2, R644.1
unnamed: Q619.1 (B), R645.2
unnamed: Q619.3 (C), R629.2, R630.2, R646.1
unnamed: Q620.1 (B), R647.2
unnamed: Q620.3 (C), R631.2, R632.2, R648.1
unnamed: Q621.1 (B), R642.2
unnamed: Q621.2 (E), R637.2
unnamed: Q622.1 (B), R644.2
unnamed: Q622.2 (E), R638.2
unnamed: Q623.1 (B), R646.2
unnamed: Q623.2 (E), R639.2
unnamed: Q624.1 (B), R648.2
unnamed: Q624.2 (E), R640.2

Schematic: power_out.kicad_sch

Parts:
C501, C507: 220µ; CP_Elec_10x10.5
C502, C504: 1n; C_0603_1608Metric
C503, C505, C508, C509, C510, C511, C512, C513, C518: 100nF; C_0603_1608Metric
C506: 100p; C_0603_1608Metric
C514, C515, C516, C517: 10n; C_0603_1608Metric
C519: 1µ; C_0603_1608Metric
D501, D502, D503, D504, D513: PMEG4010CEH; D_SOD-123F
D506, D507, D508, D509, D510, D511: BLUE; LED_0603_1608Metric
D512: RED; LED_0603_1608Metric
Q501, Q502: BTN8962TA; TO-263-7_TabPin8
R501, R502, R505, R506, R514, R515, R516, R517, R518, R519, R520, R522, R523, R524, R525, R526, R527: 10k; R_0603_1608Metric
R503, R507, R528: 1k; R_0603_1608Metric
R504, R508: t.b.d.; R_0603_1608Metric
R509: 1.2k; R_0603_1608Metric
R510, R511, R512, R513: 100k; R_0603_1608Metric
R521: 27; R_0603_1608Metric
U501: BTT6200-4ESA; Infineon_PG-TSDSO-24

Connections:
1A_Out1: C516.1, D504.1 (K), R512.2, R525.2, U501.20 (OUT1); also elsewhere on the board
1A_Out2: C515.1, D503.1 (K), R511.2, R526.2, U501.17 (OUT2); also elsewhere on the board
+BATT: C501.1, C507.1, C509.1, C510.1, C511.1, C513.1, C518.1, C519.1, Q501.7, Q502.7, U501.25 (VS); also elsewhere on the board
/Microcontroller/1A_DSEL0: R514.1; also elsewhere on the board
/Microcontroller/1A_DSEL1: R515.1; also elsewhere on the board
/Microcontroller/1A_IN0: R516.1; also elsewhere on the board
/Microcontroller/1A_IN1: R517.1; also elsewhere on the board
/Microcontroller/1A_IN2: R518.1; also elsewhere on the board
/Microcontroller/1A_IN3: R519.1; also elsewhere on the board
/Microcontroller/1A_IS: C506.1, R520.2; also elsewhere on the board
/Microcontroller/Half0_IS: C502.1, Q501.6 (IS), R503.2; also elsewhere on the board
/Microcontroller/Half0_PWM: R502.1; also elsewhere on the board
/Microcontroller/Half1_IS: C504.1, Q502.6 (IS), R507.2; also elsewhere on the board
/Microcontroller/Half1_PWM: R506.1; also elsewhere on the board
/Microcontroller/Half_INH: D512.1 (K), R501.1, R505.1; also elsewhere on the board
Half0_OUT: C508.1, C509.2, Q501.4, Q501.8, R523.2; also elsewhere on the board
Half1_OUT: C511.2, C512.1, Q502.4, Q502.8, R522.2; also elsewhere on the board
unnamed: D501.2 (A), R521.1
unnamed: D506.2 (A), R523.1
unnamed: D507.2 (A), R522.1
unnamed: D512.2 (A), R528.1
unnamed: Q501.2 (IN), R502.2
unnamed: Q501.3 (INH), R501.2
unnamed: C503.1, Q501.5 (SR), R504.2
unnamed: Q502.2 (IN), R506.2
unnamed: Q502.3 (INH), R505.2
unnamed: C505.1, Q502.5 (SR), R508.2
unnamed: R514.2, U501.8 (DSEL0)
unnamed: R515.2, U501.11 (DSEL1)
unnamed: R521.2, U501.4 (GND)
unnamed: R516.2, U501.2 (IN0)
unnamed: R517.2, U501.5 (IN1)
unnamed: R518.2, U501.9 (IN2)
unnamed: R519.2, U501.10 (IN3)
unnamed: R509.2, R520.1, U501.7 (IS)

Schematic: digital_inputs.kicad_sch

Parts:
C301, C302, C303, C304, C305, C306, C309, C310: 100pF; C_0603_1608Metric
C307, C308: 100nF; C_0603_1608Metric
D301, D302, D303, D304, D305, D306, D307, D308, D309, D310, D311, D312, D313, D314, D315, D316: BAT54S; SOT-23
R301, R302, R303, R304, R305, R306, R307, R308: 100k; R_0603_1608Metric
RN301: 10k; R_Array_Convex_8x0602
U301: 74HC595; SOIC-16_3.9x9.9mm_P1.27mm
U302: 74HCT244; SOIC-20W_7.5x12.8mm_P1.27mm

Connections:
/ADC/IN_RCLK: U301.12 (RCLK); also elsewhere on the board
/ADC/IN_SRCLK: U301.11 (SRCLK); also elsewhere on the board
/ADC/IN_SRD: U301.14 (SER); also elsewhere on the board
/ADC/IN_SRD_AIn: U301.9 (QH'); also elsewhere on the board
/Connectors/D_In_0: D301.2 (K), R301.1; also elsewhere on the board
/Connectors/D_In_1: D302.2 (K), R302.1; also elsewhere on the board
/Connectors/D_In_2: D303.2 (K), R303.1; also elsewhere on the board
/Connectors/D_In_3: D307.2 (K), R304.1; also elsewhere on the board
/Connectors/D_In_4: D308.2 (K), R305.1; also elsewhere on the board
/Connectors/D_In_5: D309.2 (K), R306.1; also elsewhere on the board
/Connectors/D_In_6: D313.2 (K), R307.1; also elsewhere on the board
/Connectors/D_In_7: D314.2 (K), R308.1; also elsewhere on the board
/Digital Inputs/D_In_0_filt: C301.1, D304.3 (COM), R301.2, U302.2 (1A0)
/Digital Inputs/D_In_0_pullup: D301.1 (A), D301.3 (COM), RN301.16 (R1.2)
/Digital Inputs/D_In_1_filt: C302.1, D305.3 (COM), R302.2, U302.4 (1A1)
/Digital Inputs/D_In_1_pullup: D302.1 (A), D302.3 (COM), RN301.15 (R2.2)
/Digital Inputs/D_In_2_filt: C303.1, D306.3 (COM), R303.2, U302.6 (1A2)
/Digital Inputs/D_In_2_pullup: D303.1 (A), D303.3 (COM), RN301.14 (R3.2)
/Digital Inputs/D_In_3V3_0: U302.18 (1Y0); also elsewhere on the board
/Digital Inputs/D_In_3V3_1: U302.16 (1Y1); also elsewhere on the board
/Digital Inputs/D_In_3V3_2: U302.14 (1Y2); also elsewhere on the board
/Digital Inputs/D_In_3V3_3: U302.12 (1Y3); also elsewhere on the board
/Digital Inputs/D_In_3V3_4: U302.3 (2Y0); also elsewhere on the board
/Digital Inputs/D_In_3V3_5: U302.5 (2Y1); also elsewhere on the board
/Digital Inputs/D_In_3V3_6: U302.7 (2Y2); also elsewhere on the board
/Digital Inputs/D_In_3V3_7: U302.9 (2Y3); also elsewhere on the board
/Digital Inputs/D_In_3_filt: C304.1, D310.3 (COM), R304.2, U302.8 (1A3)
/Digital Inputs/D_In_3_pullup: D307.1 (A), D307.3 (COM), RN301.13 (R4.2)
/Digital Inputs/D_In_4_filt: C305.1, D311.3 (COM), R305.2, U302.17 (2A0)
/Digital Inputs/D_In_4_pullup: D308.1 (A), D308.3 (COM), RN301.12 (R5.2)
/Digital Inputs/D_In_5_filt: C306.1, D312.3 (COM), R306.2, U302.15 (2A1)
/Digital Inputs/D_In_5_pullup: D309.1 (A), D309.3 (COM), RN301.11 (R6.2)
/Digital Inputs/D_In_6_filt: C309.1, D315.3 (COM), R307.2, U302.13 (2A2)
/Digital Inputs/D_In_6_pullup: D313.1 (A), D313.3 (COM), RN301.10 (R7.2)
/Digital Inputs/D_In_7_filt: C310.1, D316.3 (COM), R308.2, U302.11 (2A3)
/Digital Inputs/D_In_7_pullup: D314.1 (A), D314.3 (COM), RN301.9 (R8.2)
unnamed: RN301.1 (R1.1), U301.15 (QA)
unnamed: RN301.2 (R2.1), U301.1 (QB)
unnamed: RN301.3 (R3.1), U301.2 (QC)
unnamed: RN301.4 (R4.1), U301.3 (QD)
unnamed: RN301.5 (R5.1), U301.4 (QE)
unnamed: RN301.6 (R6.1), U301.5 (QF)
unnamed: RN301.7 (R7.1), U301.6 (QG)
unnamed: RN301.8 (R8.1), U301.7 (QH)

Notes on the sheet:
1/(2*pi*100k*100pF) = 15.9kHz
Configurable Pull-up resistors If Qn is pulled to GND the in-series diode blocks reverse voltages and the input becomes "High-Z"

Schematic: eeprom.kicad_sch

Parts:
C701: 100nF; C_0603_1608Metric
JP701: SolderJumper_2_Open; SolderJumper-2_P1.3mm_Open_Pad1.0x1.5mm
R701, R702: 10k; R_0603_1608Metric
U701: 24LC32; SOIC-8_3.9x4.9mm_P1.27mm

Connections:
/EEPROM/EEPROM_SCL: R702.2, U701.6 (SCL); also elsewhere on the board
/EEPROM/EEPROM_SDA: R701.2, U701.5 (SDA); also elsewhere on the board
/EEPROM/EEPROM_WP: JP701.2 (B), U701.7 (WP); also elsewhere on the board

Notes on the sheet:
Pin A2 wired to Vcc to allow replacement with 24LC1025

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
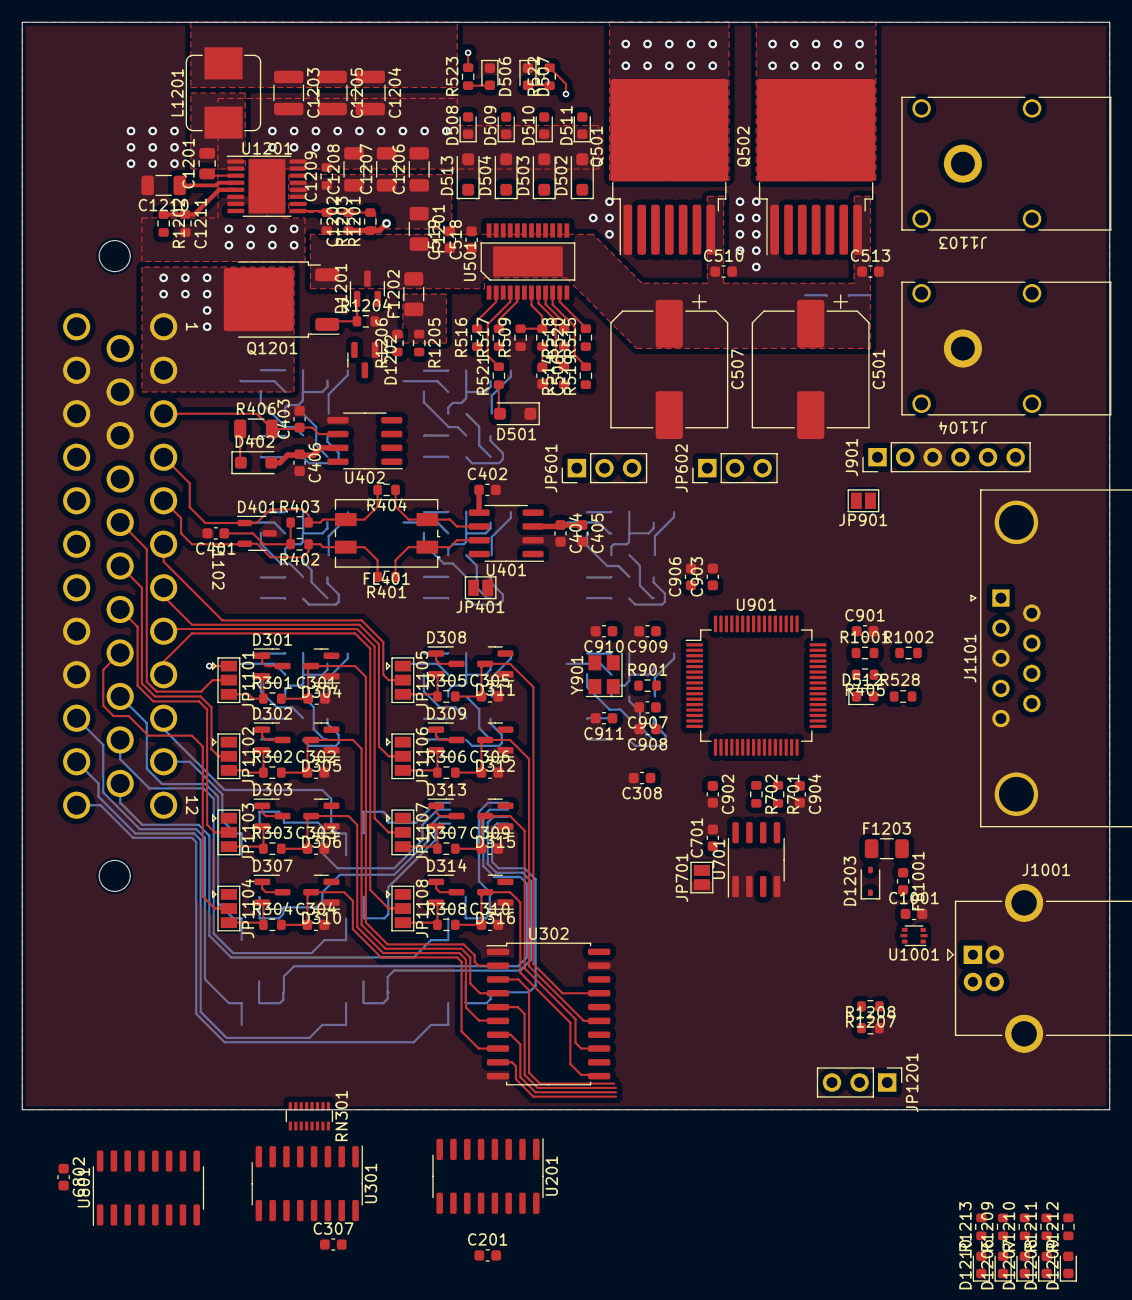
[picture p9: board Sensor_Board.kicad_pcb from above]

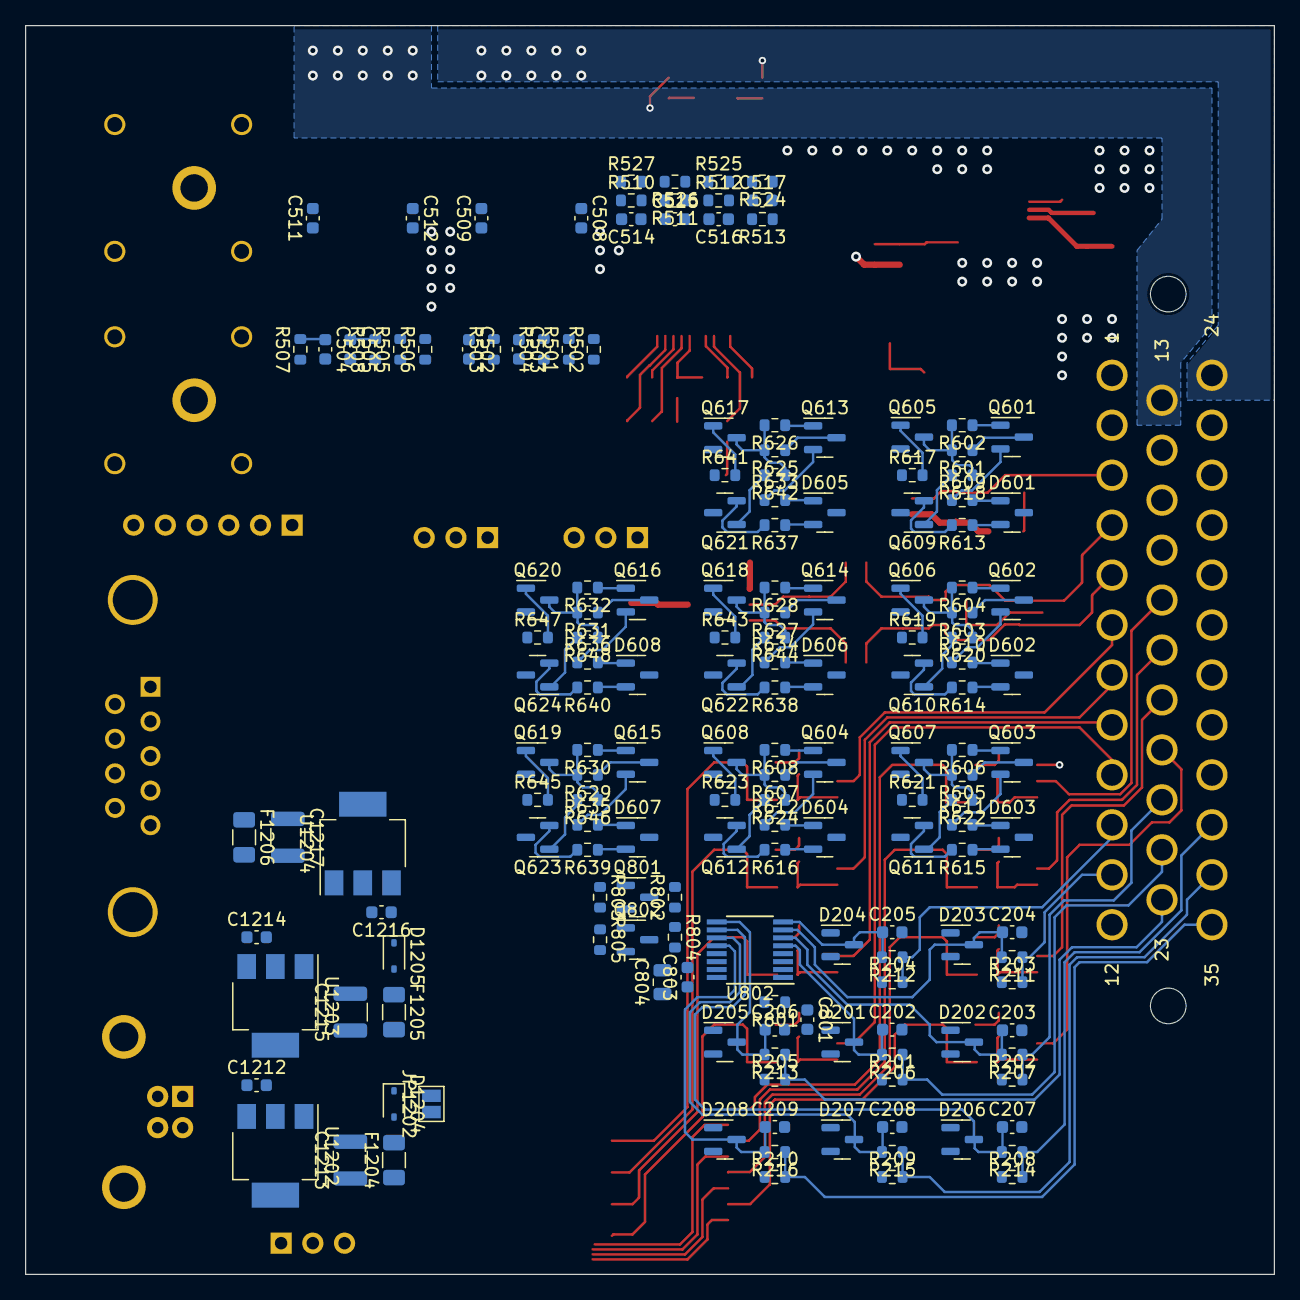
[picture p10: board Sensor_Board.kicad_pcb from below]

Board: 4 copper layers, 100.0 x 100.0 mm, 338 parts (166 on the bottom side), 266 nets.

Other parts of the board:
C901, C902, C903, C904, C909, C910, C911, C1001: 100nF; C_0603_1608Metric
C906: 4.7µ; C_0603_1608Metric
C907: 10n; C_0603_1608Metric
C908: 1µ; C_0603_1608Metric
D402: PMEG4010CEH; D_SOD-123F
D1202: BAT54S; SOT-23
D1203, D1204, D1205: BAT60A; D_SOD-323
D1206, D1207, D1208, D1209, D1210: GREEN; LED_0603_1608Metric
R801: 2k; R_0603_1608Metric
R1209, R1213: 10k; R_0603_1608Metric
R1210, R1211, R1212: 1k; R_0603_1608Metric

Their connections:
+5V: D1203.1 (K), D1205.1 (K), R1211.2; also elsewhere on the board
+5VA: R801.1, R1210.2; also elsewhere on the board
+BATT: R1213.2; also elsewhere on the board
/Microcontroller/VS_drive: D1202.3 (COM); also elsewhere on the board
unnamed 151: D1203.2 (A); also elsewhere on the board
unnamed 152: D1204.2 (A); also elsewhere on the board
unnamed 153: D1204.1 (K); also elsewhere on the board
unnamed 154: D1205.2 (A); also elsewhere on the board
unnamed: D1206.2 (A), R1209.1
unnamed: D1207.2 (A), R1210.1
unnamed: D1208.2 (A), R1211.1
unnamed: D1209.2 (A), R1212.1
unnamed: D1210.2 (A), R1213.1
unnamed 245: R801.2; also elsewhere on the board

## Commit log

2023-12-16 cleaned up repository
    [Sensor_Board.csv]
2023-12-16 added net-classes
    [Sensor_Board.kicad_sch, adc.kicad_sch, analog_inputs.kicad_sch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]
2023-12-17 completed schematic
    [Sensor_Board.kicad_sch, adc.kicad_sch, analog_inputs.kicad_sch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]
2023-12-18 placed components and began routing
    [Sensor_Board.kicad_pcb, connectors.kicad_sch, digital_inputs.kicad_sch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]
2023-12-20 majority of layout done
    [adc.kicad_sch, digital_inputs.kicad_sch, microcontroller.kicad_sch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]
2023-12-20 generated BOM
2023-12-23 fixed oscillator and component values
    [adc.kicad_sch, microcontroller.kicad_sch, power_out.kicad_sch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]
2023-12-26 hierarchical sheets for digital I/O and replaced power supply jumpers with relays
    [Sensor_Board.kicad_sch, adc.kicad_sch, analog_inputs.kicad_sch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]
2024-01-04 added missing values and possible improvements
    [digital_inputs.kicad_sch, microcontroller.kicad_sch, power_out.kicad_sch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]
